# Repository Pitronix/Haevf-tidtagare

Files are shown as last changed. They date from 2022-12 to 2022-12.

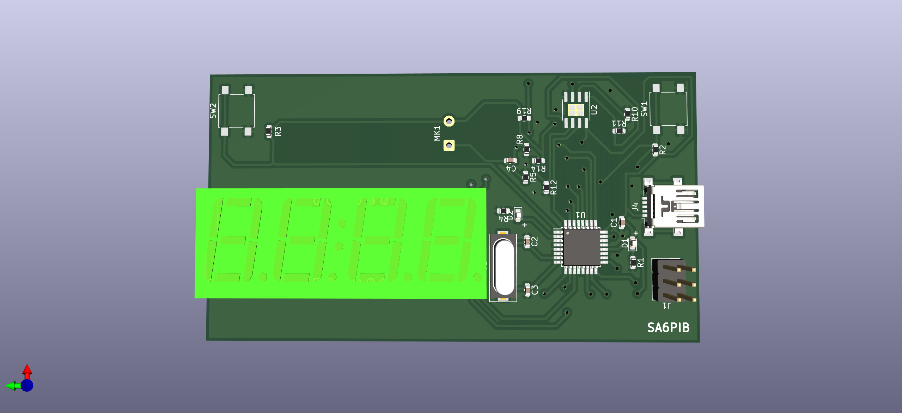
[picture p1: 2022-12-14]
haevfTimerV1.png

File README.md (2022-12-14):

# Hävf-Timer
 En hävf tidtagare i kreditkortsformat, perfekt när man vill utmana sina vänner eller göra övningshävf då det även finns en inbyggd självstart funktion.
 ## Användning:
1. Tidtagaren sätts i **tävlingsmod** när den vänstra knappen trycks ner en gång. Tidtagningen startas och stoppas med ett slag på bordet. Nollställning görs på den vänstra knappen.
2. Tidtagaren sätts i **träningsmod** genom att hålla inne den vänsta knappen. En nedräkning från 5 sekunder startas och tiden börjar räkna upp automatisk. Tidtagningen stoppas med ett slag på bordet och nollställs med ett tryck på den vänstra knappen.

IMG_7664 (2)

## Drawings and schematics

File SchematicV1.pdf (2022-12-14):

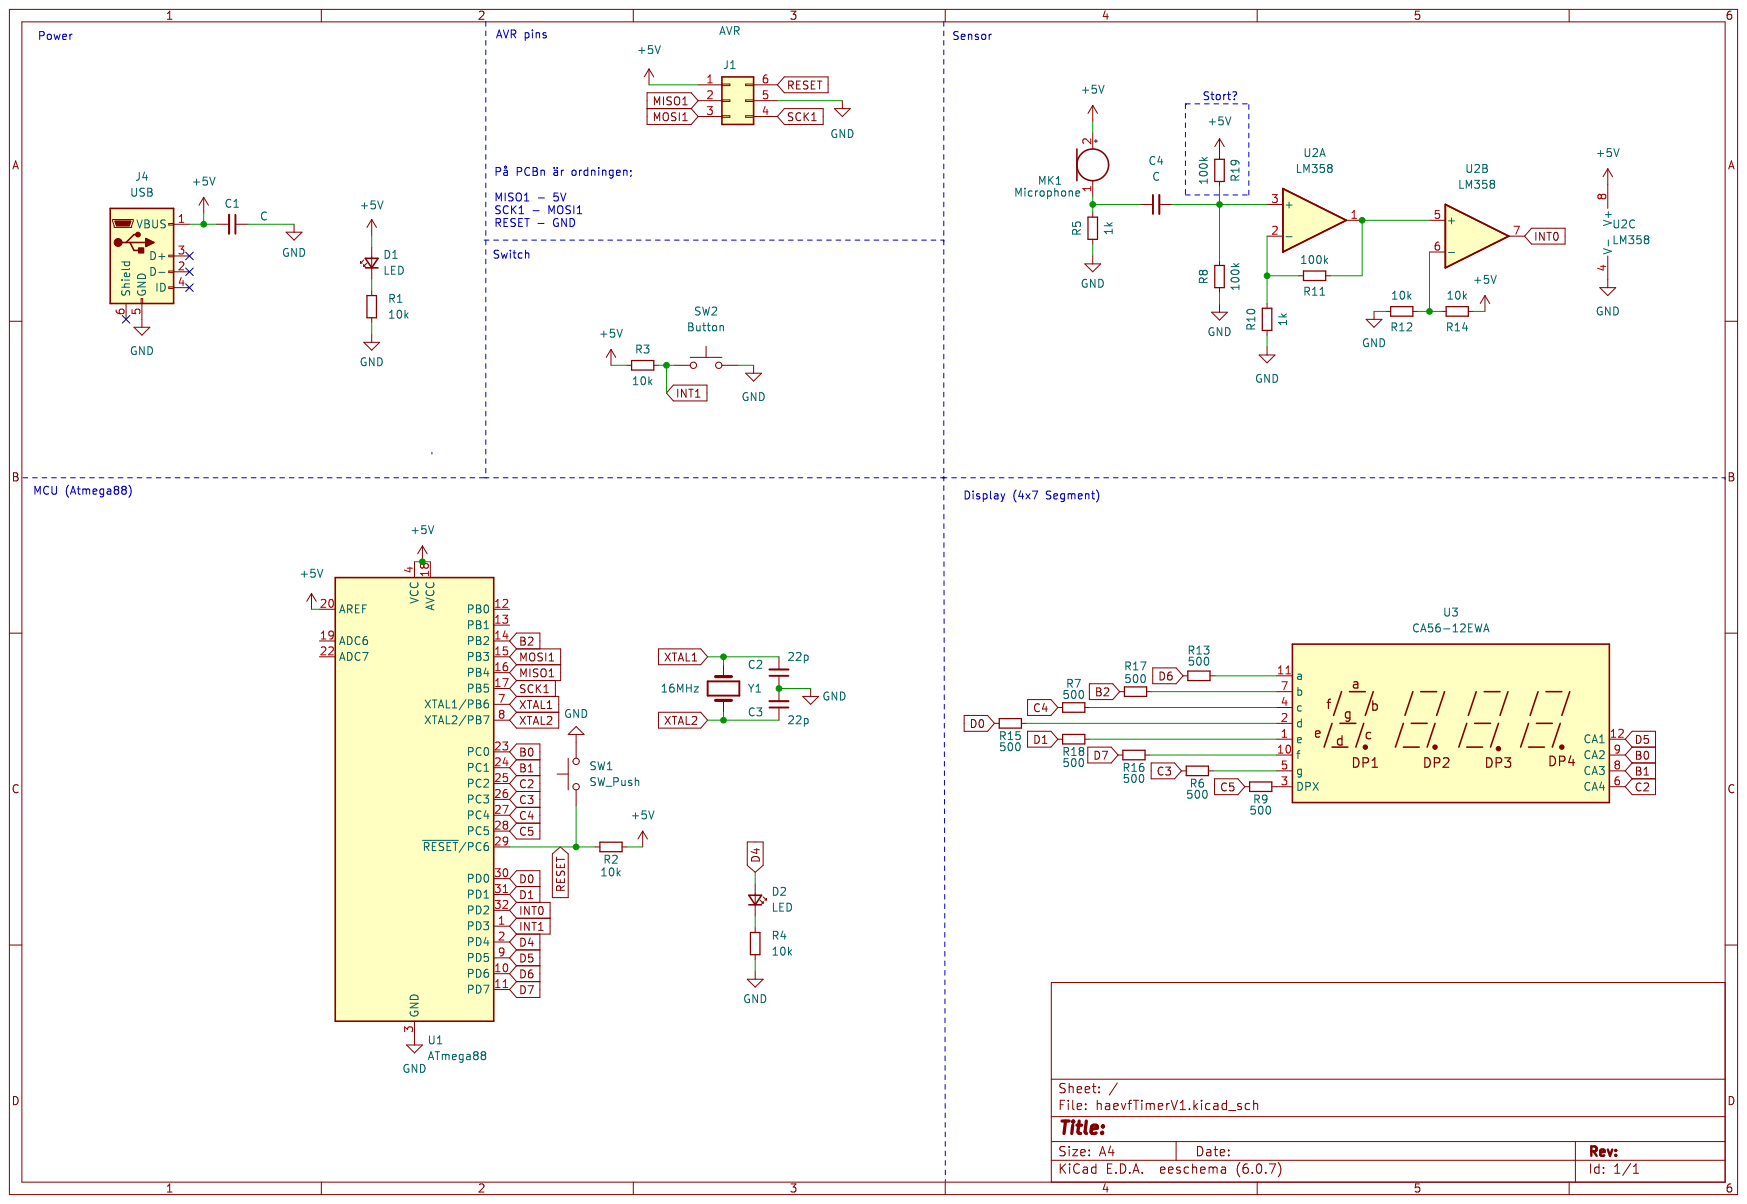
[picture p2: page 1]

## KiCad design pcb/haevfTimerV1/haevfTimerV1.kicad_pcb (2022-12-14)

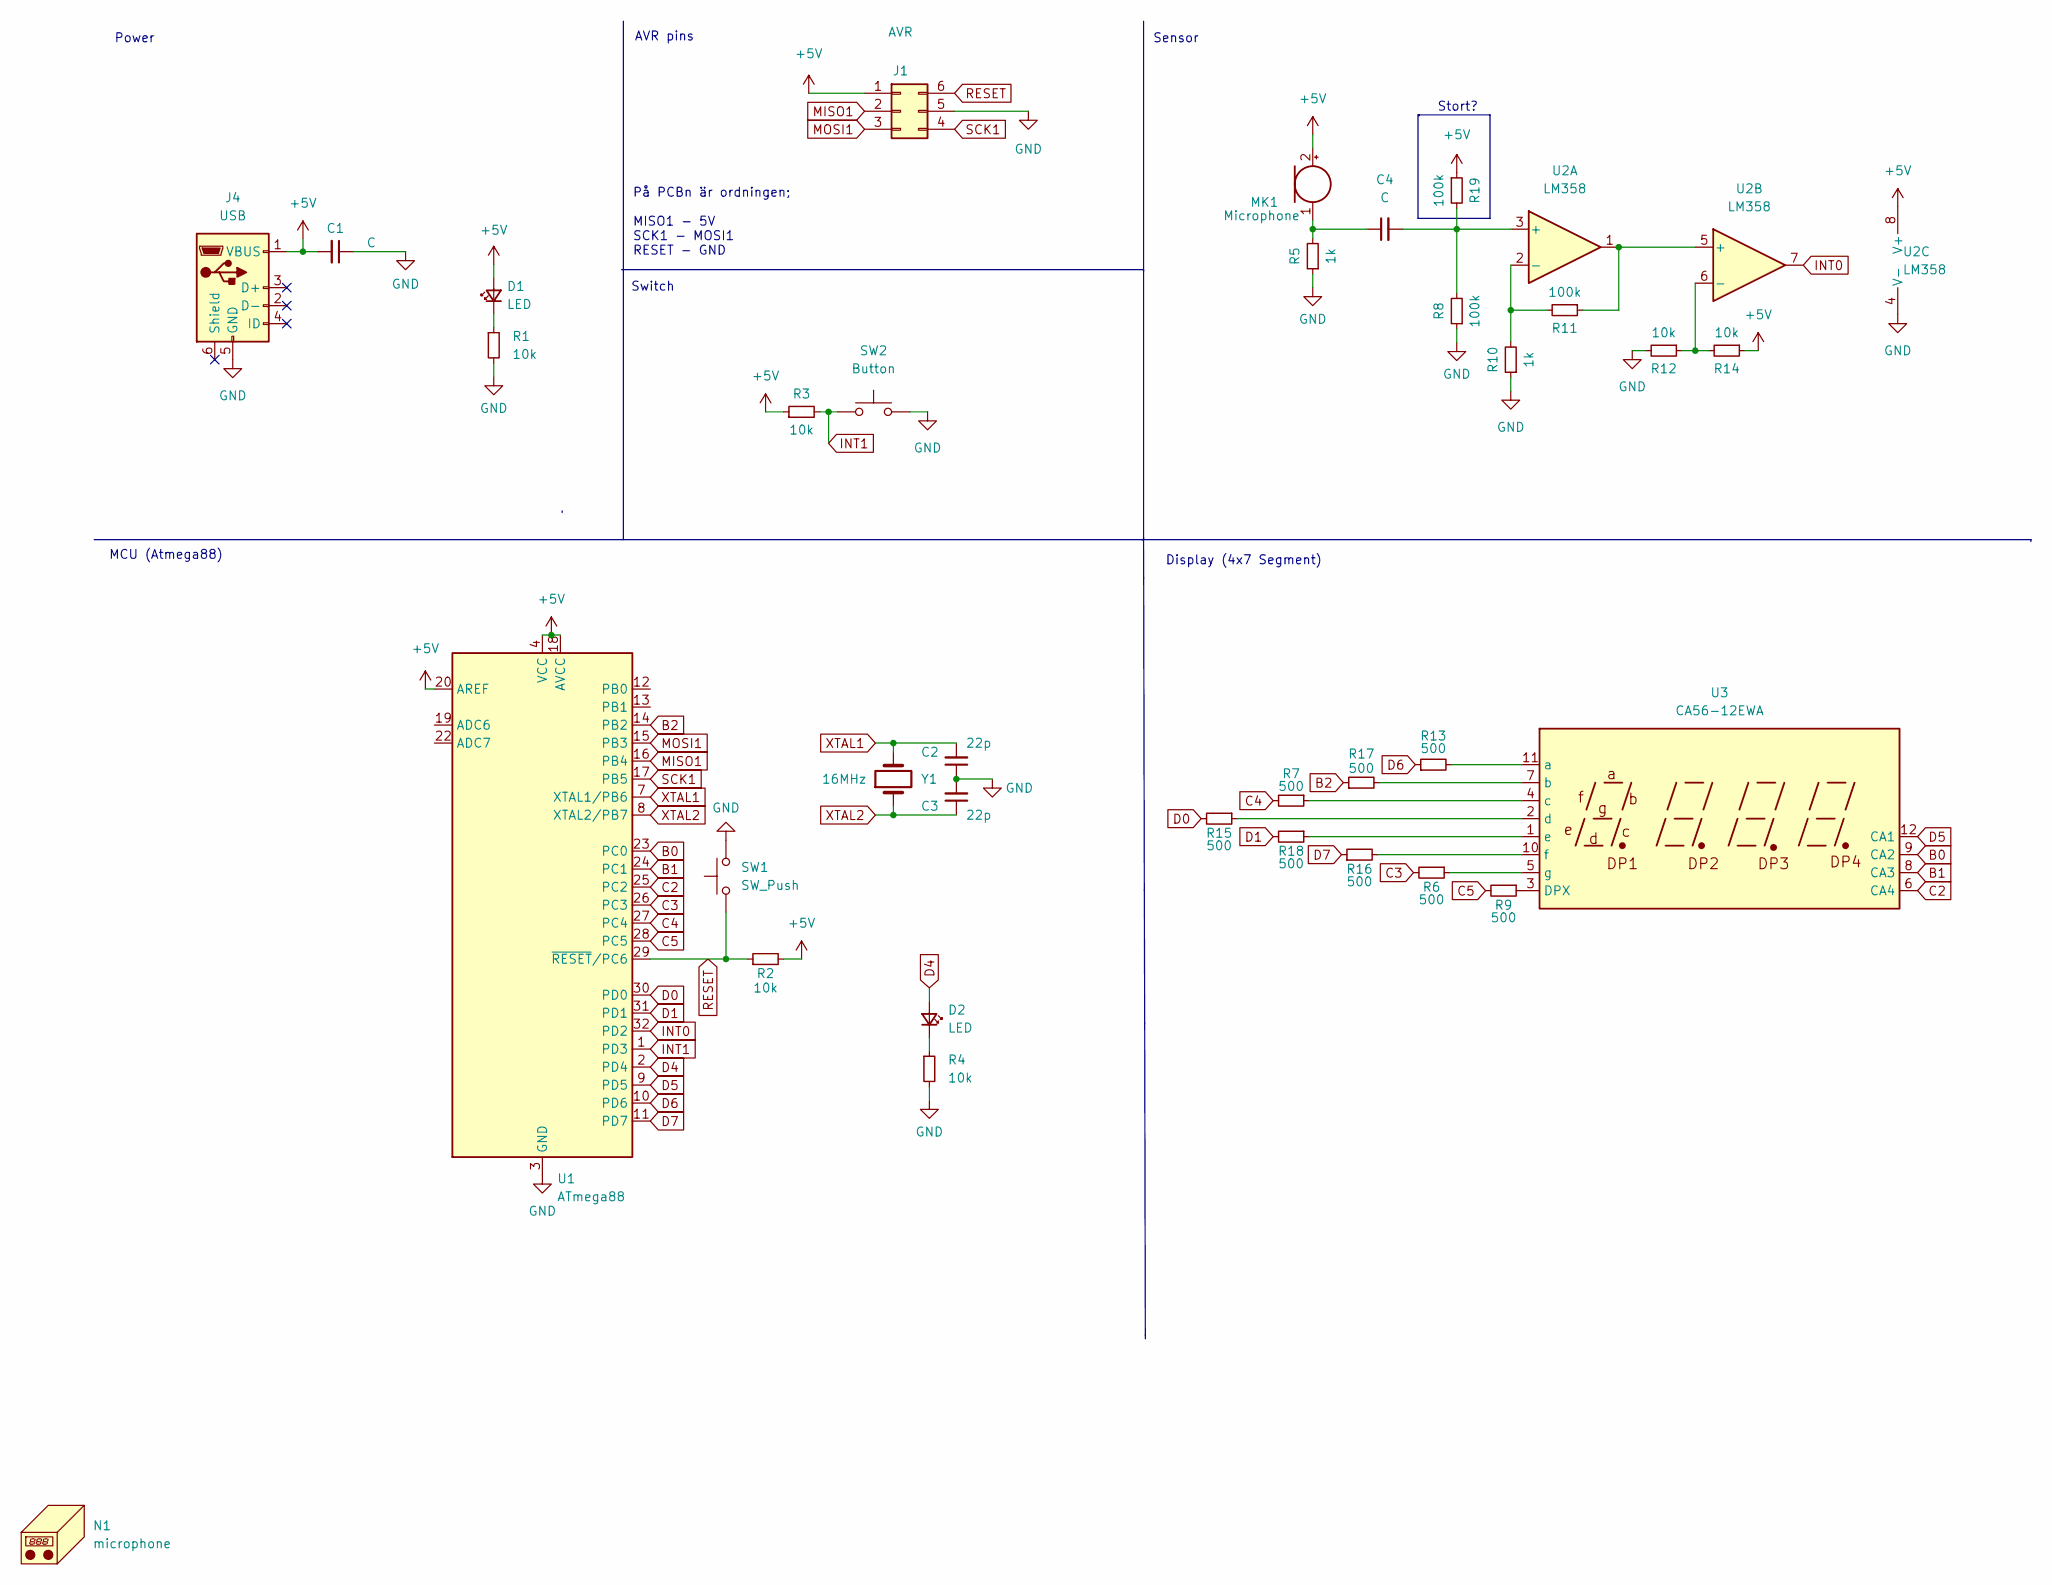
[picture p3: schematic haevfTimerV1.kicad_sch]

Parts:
C1, C4: C; C_0603_1608Metric
C2, C3: 22p; C_0603_1608Metric
D1, D2: LED; LED_0603_1608Metric
J1: AVR; PinHeader_2x03_P2.54mm_Vertical
J4: USB; USB_Mini-B_Lumberg_2486_01_Horizontal
MK1: Microphone; SolderWire-0.5sqmm_1x02_P4.6mm_D0.9mm_OD2.1mm
N1: microphone; Symbol_CC-PublicDomain_CopperTop_Small
R1, R2, R3, R4, R12, R14: 10k; R_0603_1608Metric
R5, R10: 1k; R_0603_1608Metric
R6, R7, R9, R13, R15, R16, R17, R18: 500; R_0603_1608Metric
R8, R11, R19: 100k; R_0603_1608Metric
SW1: SW_Push; SW_SPST_B3S-1000
SW2: Button; SW_SPST_B3S-1000
U1: ATmega88; TQFP-32_7x7mm_P0.8mm
U2: LM358; SOIC-8-1EP_3.9x4.9mm_P1.27mm_EP2.29x3mm
U3: CA56-12EWA
Y1: 16MHz; Crystal_SMD_HC49-SD

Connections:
+5V: C1.2, D1.2 (A), J1.1, J4.1 (VBUS), MK1.2 (+), R2.2, R3.1, R14.1, R19.1, U1.4 (VCC), U1.6 (VCC), U1.18 (AVCC), U1.20 (AREF), U2.8 (V+)
B0: U1.23 (PC0), U3.9 (CA2)
B1: U1.24 (PC1), U3.8 (CA3)
B2: R17.1, U1.14 (PB2)
C2: U1.25 (PC2), U3.6 (CA4)
C3: R6.2, U1.26 (PC3)
C4: R7.2, U1.27 (PC4)
C5: R9.2, U1.28 (PC5)
D0: R15.2, U1.30 (PD0)
D1: R18.2, U1.31 (PD1)
D4: D2.2 (A), U1.2 (PD4)
D5: U1.9 (PD5), U3.12 (CA1)
D6: R13.1, U1.10 (PD6)
D7: R16.1, U1.11 (PD7)
GND: C1.1, C2.1, C3.2, J1.5, J4.5 (GND), R1.2, R4.2, R5.1, R8.1, R10.1, R12.2, SW1.2, SW2.2, U1.3 (GND), U1.5 (GND), U1.21 (GND), U2.4 (V-)
INT0: U1.32 (PD2), U2.7
INT1: R3.2, SW2.1, U1.1 (PD3)
MISO1: J1.2, U1.16 (PB4)
MOSI1: J1.3, U1.15 (PB3)
unnamed: C4.1, MK1.1 (-), R5.2
unnamed: C4.2, R8.2, R19.2, U2.3 (+)
unnamed: D1.1 (K), R1.1
unnamed: D2.1 (K), R4.1
unnamed: R6.1, U3.5 (g)
unnamed: R7.1, U3.4 (c)
unnamed: R9.1, U3.3 (DPX)
unnamed: R10.2, R11.2, U2.2 (-)
unnamed: R11.1, U2.1, U2.5 (+)
unnamed: R12.1, R14.2, U2.6 (-)
unnamed: R13.2, U3.11 (a)
unnamed: R15.1, U3.2 (d)
unnamed: R16.2, U3.10 (f)
unnamed: R17.2, U3.7 (b)
unnamed: R18.1, U3.1 (e)
RESET: J1.6, R2.1, SW1.1, U1.29 (~RESET/PC6)
SCK1: J1.4, U1.17 (PB5)
XTAL1: C2.2, U1.7 (XTAL1/PB6), Y1.2
XTAL2: C3.1, U1.8 (XTAL2/PB7), Y1.1

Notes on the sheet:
Display (4x7 Segment)
Sensor
Switch
AVR pins
MCU (Atmega88)
Power
Stort?
På PCBn är ordningen; MISO1 - 5V SCK1 - MOSI1 RESET - GND

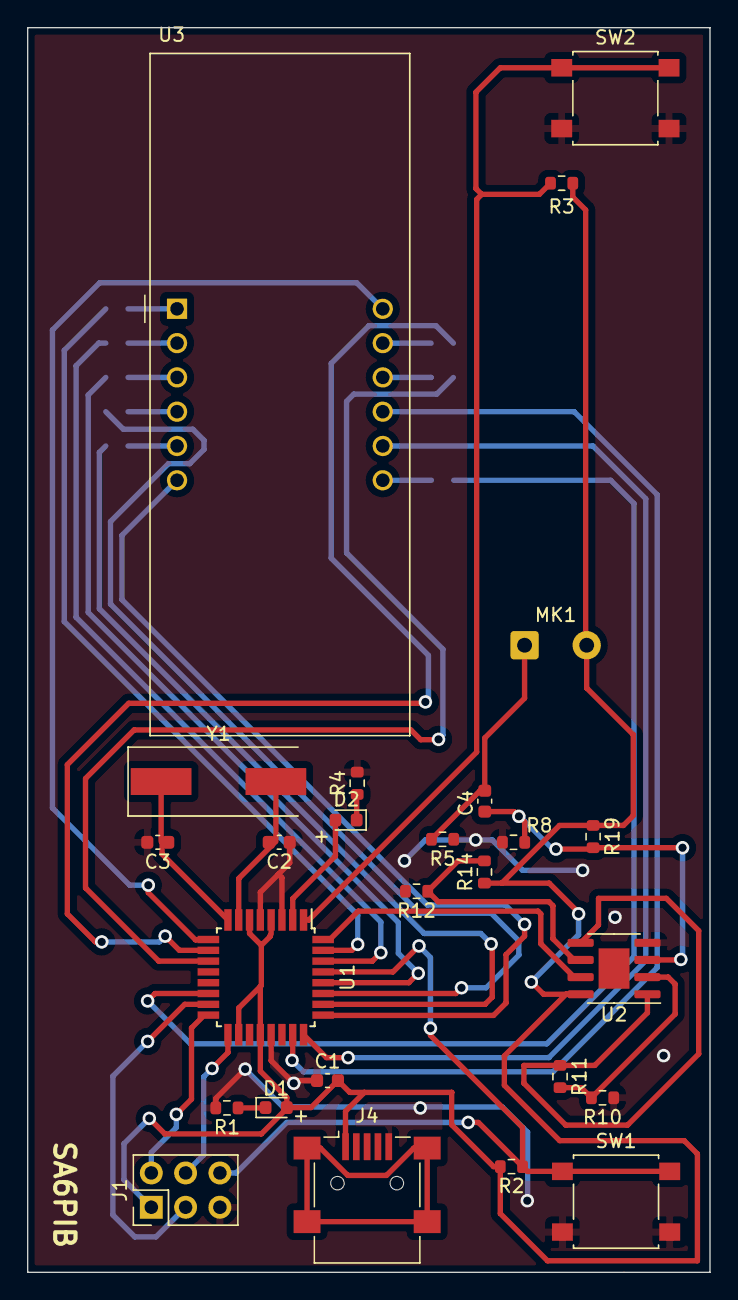
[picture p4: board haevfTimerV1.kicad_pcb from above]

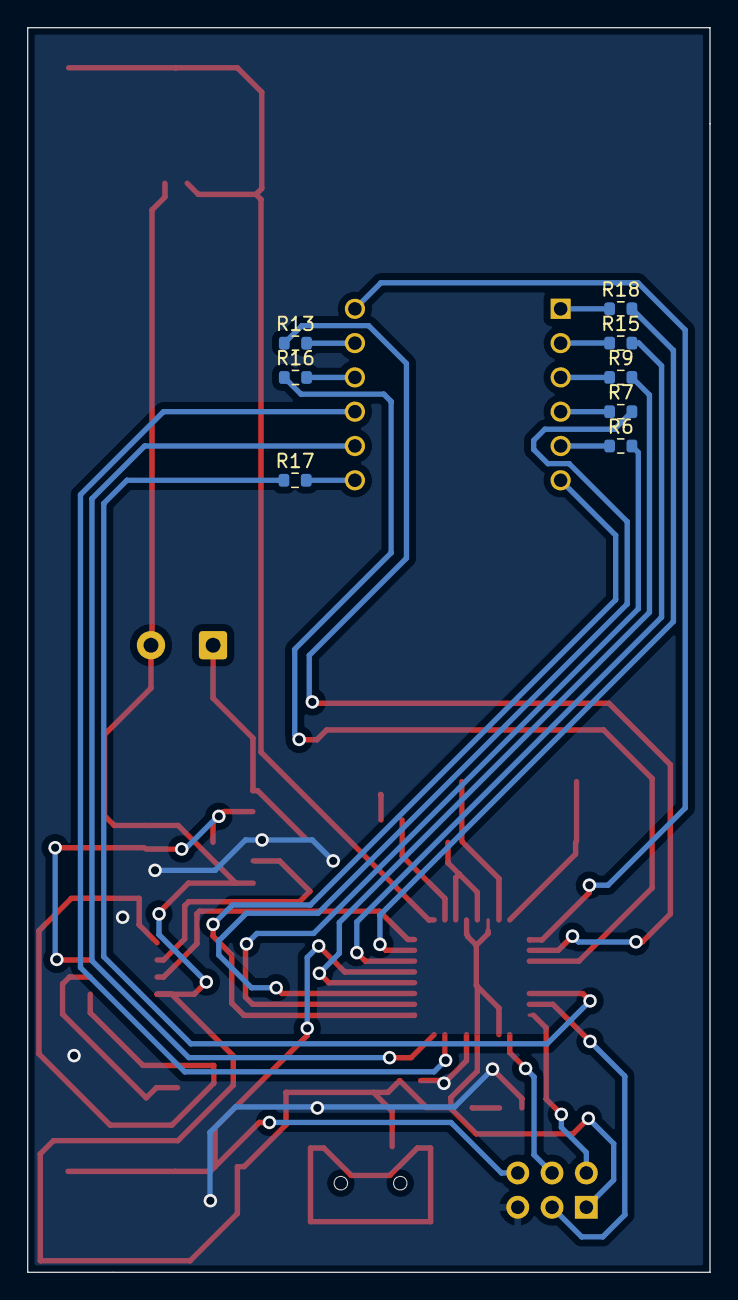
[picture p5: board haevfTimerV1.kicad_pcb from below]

Board: 2 copper layers, 50.5 x 92.2 mm, 34 parts (8 on the bottom side), 38 nets.

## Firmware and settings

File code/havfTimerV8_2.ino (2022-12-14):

//Version 8.2 Final

int pinA = 6;
int pinB = 10;
int pinC = A4;
int pinD = 0;
int pinE = 1;
int pinF = 7;
int pinG = A3;
int pinH = A5;

int d1 = 5;
int d2 = A0;
int d3 = A1;
int d4 = A2;

int mic = 2;
int button = 3;

int led = 4;

int i = 1;
int x = 1;

unsigned long startTime = 0;
unsigned long stopTime = 0;

long previousMillis = 0;
long previousMillis2 = 0;

unsigned long holdTime;

boolean micFlag = false;
boolean buttonFlag = true;
boolean stopFlag = false;

unsigned long endTime = 0;

void setup() {
  attachInterrupt(digitalPinToInterrupt(button), buttonInterrupt, CHANGE);
  attachInterrupt(digitalPinToInterrupt(mic), micInterrupt, CHANGE);

  pinMode(pinA, OUTPUT);
  pinMode(pinB, OUTPUT);
  pinMode(pinC, OUTPUT);
  pinMode(pinD, OUTPUT);
  pinMode(pinE, OUTPUT);
  pinMode(pinF, OUTPUT);
  pinMode(pinG, OUTPUT);
  pinMode(pinH, OUTPUT);

  pinMode(d1, OUTPUT);
  pinMode(d2, OUTPUT);
  pinMode(d3, OUTPUT);
  pinMode(d4, OUTPUT);

  pinMode(led, OUTPUT);

  zeroDisplay();

}

void loop() {
  if (buttonFlag) {
    digitalWrite(led, LOW);
    if (!digitalRead(button)) {
      if (millis() - holdTime >= 1000) {
        startCountdown(5);
        buttonFlag = false;
      }
    }

    zeroDisplay();

  }

  else if (micFlag) {
    multiplex((millis() - startTime), 2);
  }

  else if (stopFlag) {
    multiplex(( endTime ), 2 );
  }
}





// Button interrupt function
void buttonInterrupt() {
  buttonFlag = true;
  stopFlag = false;
  holdTime = millis();
}




// Microphone interrupt function

void micInterrupt() {
  if (!micFlag && !stopFlag) {
    if ( millis() - holdTime > 1000 ) {
      startTime = millis();
      micFlag = true;
      buttonFlag = false;
    }
  }

  if (micFlag && (millis() - startTime >= 500)) {
    stopTime = millis();
    micFlag = false;
    stopFlag = true;
    endTime = stopTime - startTime;
  }
}




// Fungerar inte
/*
  bool longButtonPress() {
  if (!digitalRead(button)) {
    if ( millis() - holdTime >= 1000 ) {
      digitalWrite(led, HIGH);
      return true;
    } else {
      return false;
    }
  }
  }
*/


void startCountdown(int seconds) {
  digitalWrite(d1, LOW);
  digitalWrite(d2, LOW);
  digitalWrite(d3, LOW);
  digitalWrite(d4, LOW);

  int n = (seconds + 1);
  while (n > 0) {
    unsigned long currentMillis2 = millis();
    if (currentMillis2 - previousMillis2 >= 1000) {
      previousMillis2 = currentMillis2;
      n--;
    }
    renderDigit(n);
  }
  startTime = millis();
  micFlag = true;
}




// Multiplexes four displays
void multiplex(unsigned long number, int framerate) {
  unsigned long currentMillis = millis();
  if (currentMillis - previousMillis >= framerate) {
    previousMillis = currentMillis;
    if (x > 4) {
      x = 1;
    }
    else {
      int lengthCount = 0;
      unsigned long divnumber = number;

      while (divnumber != 0) {
        divnumber /= 10;
        lengthCount++;
      }
      int one = number / pow(10, (lengthCount - 1) );
      int two = (number / pow(10, (lengthCount - 2) )) - (one * 10);
      int three = (number / pow(10, (lengthCount - 3) )) - ((one * 100) + (two * 10));
      int four = (number / pow(10, (lengthCount - 4) )) - ((one * 1000) + (two * 100) + (three * 10));

      segmentX(x);

      if (x == 1) {
        renderDigit(one);
        // if millis > 1000
        if (micFlag) {
          if (millis() - startTime > 1000 && millis() - startTime < 10000) {
            digitalWrite(pinH, HIGH);
          } else {
            digitalWrite(pinH, LOW);
          }
        } else if (stopFlag) {
          if (endTime > 1000 && endTime < 10000) {
            digitalWrite(pinH, HIGH);
          } else {
            digitalWrite(pinH, LOW);
          }
        }
      }
      else if (x == 2) {
        renderDigit(two);
        if (micFlag) {
          if (millis() - startTime > 10000 && millis() - startTime < 100000) {
            digitalWrite(pinH, HIGH);
          } else {
            digitalWrite(pinH, LOW);
          }

        } else if (stopFlag) {
          if (endTime > 10000 && endTime < 100000) {
            digitalWrite(pinH, HIGH);
          } else {
            digitalWrite(pinH, LOW);
          }
        }
      }
      else if (x == 3) {
        renderDigit(three);
        if (micFlag) {
          if (millis() - startTime > 100000 && millis() - startTime < 1000000 && !stopFlag) {
            digitalWrite(pinH, HIGH);
          } else {
            digitalWrite(pinH, LOW);
          }
        } else if (stopFlag) {
          if (endTime > 100000 && endTime < 1000000) {
            digitalWrite(pinH, HIGH);
          } else {
            digitalWrite(pinH, LOW);
          }
        }
      }
      else if (x == 4) {
        renderDigit(four);
        digitalWrite(pinH, LOW);
      }
      x++;
    }
  }
}




// Function to activate targit display, 1 is the most left display
void segmentX(int segment) {
  if (segment == 1) {
    digitalWrite(d1, LOW);
    digitalWrite(d2, HIGH);
    digitalWrite(d3, HIGH);
    digitalWrite(d4, HIGH);
  }
  else if (segment == 2) {
    digitalWrite(d1, HIGH);
    digitalWrite(d2, LOW);
    digitalWrite(d3, HIGH);
    digitalWrite(d4, HIGH);
  }
  else if (segment == 3) {
    digitalWrite(d1, HIGH);
    digitalWrite(d2, HIGH);
    digitalWrite(d3, LOW);
    digitalWrite(d4, HIGH);
  }
  else if (segment == 4) {
    digitalWrite(d1, HIGH);
    digitalWrite(d2, HIGH);
    digitalWrite(d3, HIGH);
    digitalWrite(d4, LOW);
  }
}


// Sets all displays to zero
void zeroDisplay() {
  digitalWrite(d1, LOW);
  digitalWrite(d2, LOW);
  digitalWrite(d3, LOW);
  digitalWrite(d4, LOW);
  digitalWrite(pinA, HIGH);
  digitalWrite(pinB, HIGH);
  digitalWrite(pinC, HIGH);
  digitalWrite(pinD, HIGH);
  digitalWrite(pinE, HIGH);
  digitalWrite(pinF, HIGH);
  digitalWrite(pinG, LOW);
  digitalWrite(pinH, LOW);
}

// DigitMapping
void renderDigit(int x) {
  //0
  if (x == 0) {
    digitalWrite(pinA, HIGH);
    digitalWrite(pinB, HIGH);
    digitalWrite(pinC, HIGH);
    digitalWrite(pinD, HIGH);
    digitalWrite(pinE, HIGH);
    digitalWrite(pinF, HIGH);
    digitalWrite(pinG, LOW);
  }
  //1
  else if (x == 1) {
    digitalWrite(pinA, LOW);
    digitalWrite(pinB, HIGH);
    digitalWrite(pinC, HIGH);
    digitalWrite(pinD, LOW);
    digitalWrite(pinE, LOW);
    digitalWrite(pinF, LOW);
    digitalWrite(pinG, LOW);
  }
  //2
  else if (x == 2) {
    digitalWrite(pinA, HIGH);
    digitalWrite(pinB, HIGH);
    digitalWrite(pinC, LOW);
    digitalWrite(pinD, HIGH);
    digitalWrite(pinE, HIGH);
    digitalWrite(pinF, LOW);
    digitalWrite(pinG, HIGH);
  }
  //3
  else if (x == 3) {
    digitalWrite(pinA, HIGH);
    digitalWrite(pinB, HIGH);
    digitalWrite(pinC, HIGH);
    digitalWrite(pinD, HIGH);
    digitalWrite(pinE, LOW);
    digitalWrite(pinF, LOW);
    digitalWrite(pinG, HIGH);
  }

  //4
  else if (x == 4) {
    digitalWrite(pinA, LOW);
    digitalWrite(pinB, HIGH);
    digitalWrite(pinC, HIGH);
    digitalWrite(pinD, LOW);
    digitalWrite(pinE, LOW);
    digitalWrite(pinF, HIGH);
    digitalWrite(pinG, HIGH);
  }
  //5
  else if (x == 5) {
    digitalWrite(pinA, HIGH);
    digitalWrite(pinB, LOW);
    digitalWrite(pinC, HIGH);
    digitalWrite(pinD, HIGH);
    digitalWrite(pinE, LOW);
    digitalWrite(pinF, HIGH);
    digitalWrite(pinG, HIGH);
  }
  //6
  else if (x == 6) {
    digitalWrite(pinA, HIGH);
    digitalWrite(pinB, LOW);
    digitalWrite(pinC, HIGH);
    digitalWrite(pinD, HIGH);
    digitalWrite(pinE, HIGH);
    digitalWrite(pinF, HIGH);
    digitalWrite(pinG, HIGH);
  }
  //7
  else if (x == 7) {
    digitalWrite(pinA, HIGH);
    digitalWrite(pinB, HIGH);
    digitalWrite(pinC, HIGH);
    digitalWrite(pinD, LOW);
    digitalWrite(pinE, LOW);
    digitalWrite(pinF, LOW);
    digitalWrite(pinG, LOW);
  }
  //8
  else if (x == 8) {
    digitalWrite(pinA, HIGH);
    digitalWrite(pinB, HIGH);
    digitalWrite(pinC, HIGH);
    digitalWrite(pinD, HIGH);
    digitalWrite(pinE, HIGH);
    digitalWrite(pinF, HIGH);
    digitalWrite(pinG, HIGH);
  }
  //9
  else if (x == 9) {
    digitalWrite(pinA, HIGH);
    digitalWrite(pinB, HIGH);
    digitalWrite(pinC, HIGH);
    digitalWrite(pinD, LOW);
    digitalWrite(pinE, LOW);
    digitalWrite(pinF, HIGH);
    digitalWrite(pinG, HIGH);
  }
}
